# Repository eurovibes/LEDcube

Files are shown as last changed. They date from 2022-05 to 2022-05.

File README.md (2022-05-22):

<!-- SPDX-FileCopyrightText: 2021 Benedikt Spranger <b.spranger@linutronix.de> -->
<!-- SPDX-License-Identifier: CERN-OHL-S-2.0 -->


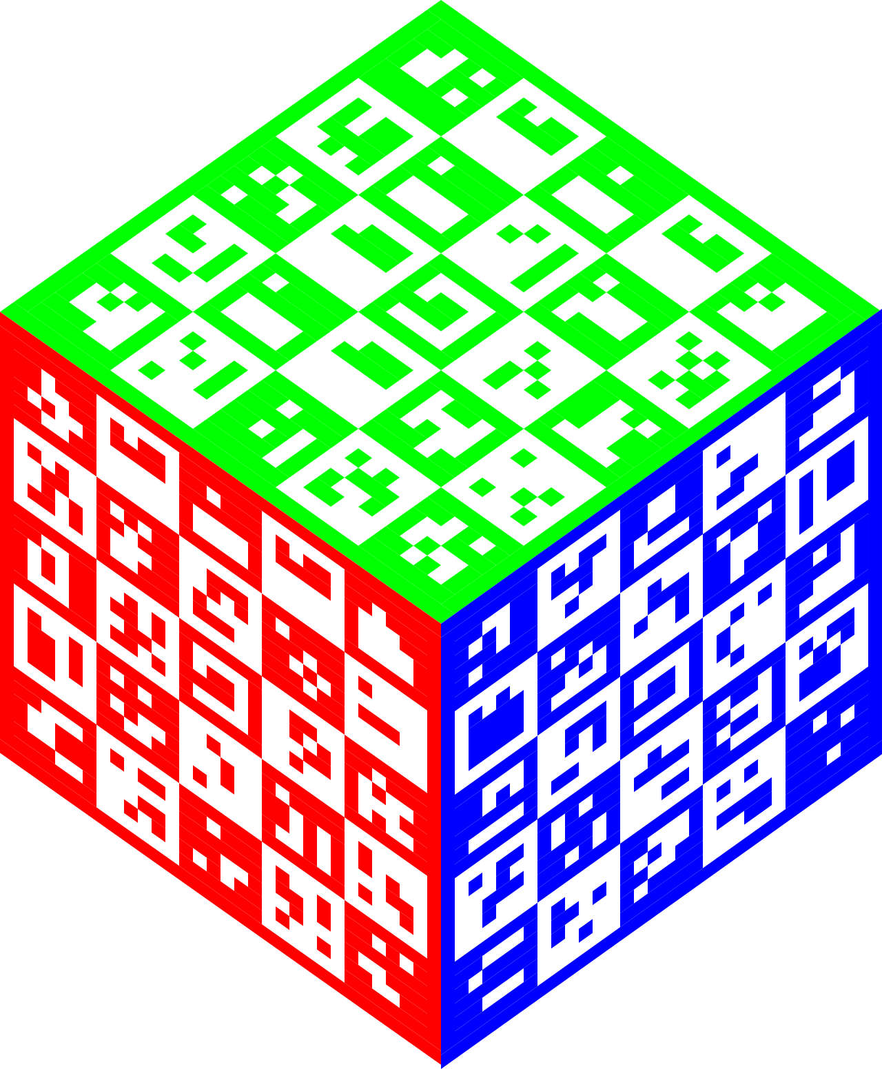
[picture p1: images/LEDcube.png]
LEDcube logo


# LEDcube -  Olimex STMP157-OLinuXino-LIME2 Sensor and Motor shield

## License rules

LEDcube is provided under the terms of the CERN-OHL-S license
version 2 as provided in the LICENSES/CERN-OHL-S-2.0 file.

Instead of adding license boilerplates to the individual files,
LEDcube uses SPDX license identifiers, which are machine parseable
and considered legaly equivalent.

The SPDX license identifier in LEDcube shall be added at the first
possible line in a file which can contain a comment. This is normally the
first line except for scripts. Scripts require the #!PATH_TO_INTERPRETER tag
in the first line; place the SPDX identifier into the second line.

The SPDX license identifier is added in form of a comment.

## Copyright and License

> Copyright Benedikt Spranger 2021.
> This source describes Open Hardware and is licensed under the CERNOHL-S v2.
> You may redistribute and modify this source and make products using it
> under the terms of the CERN-OHL-S v2 (https://ohwr.org/cern ohl s v2.txt ).
> This source is distributed WITHOUT ANY EXPRESS OR IMPLIED WARRANTY, INCLUDING
> OF MERCHANTABILITY, SATISFACTORY QUALITY AND FITNESS FOR A PARTICULAR PURPOSE.
> Please see the CERN-OHL-S v2 for applicable conditions.
> Source location: https://github.com/eurovibes/LEDcube
> As per CERN-OHL-S v2 section 4, should You produce hardware based
> on this source, You must where practicable maintain the Source Location
> visible on the external case of the LEDcube or other products you
> make using this source.

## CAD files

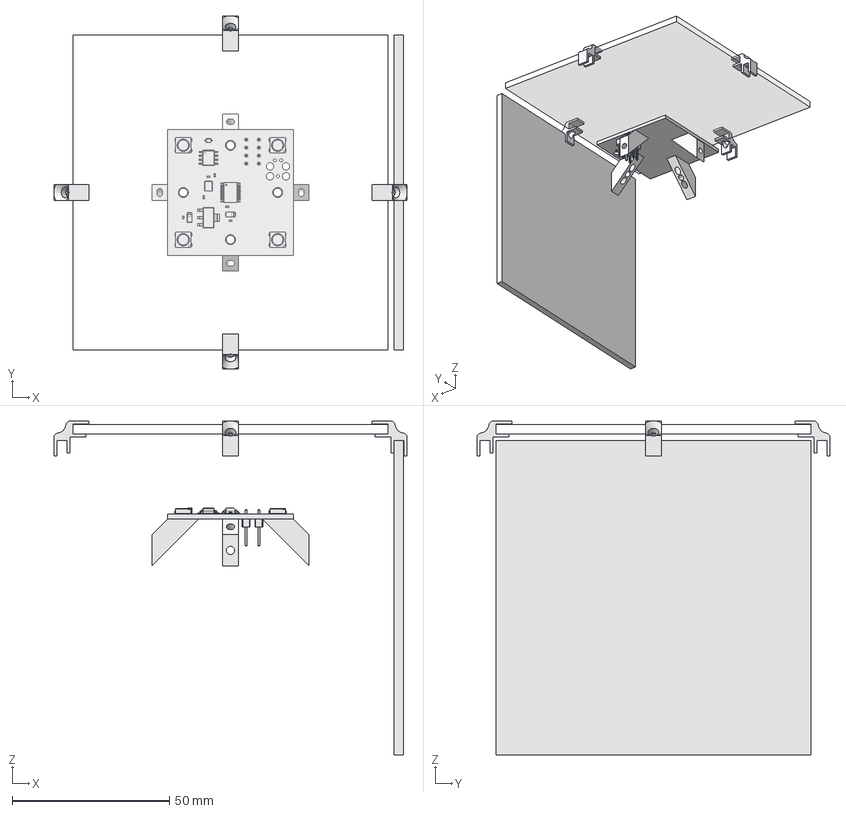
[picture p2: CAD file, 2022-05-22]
enclosure/LEDcube.FCStd
112.2 x 112.2 x 106.1 mm
LEDcube
Plexi
Halter
Halter1
Halter2
Halter3
Plexi1

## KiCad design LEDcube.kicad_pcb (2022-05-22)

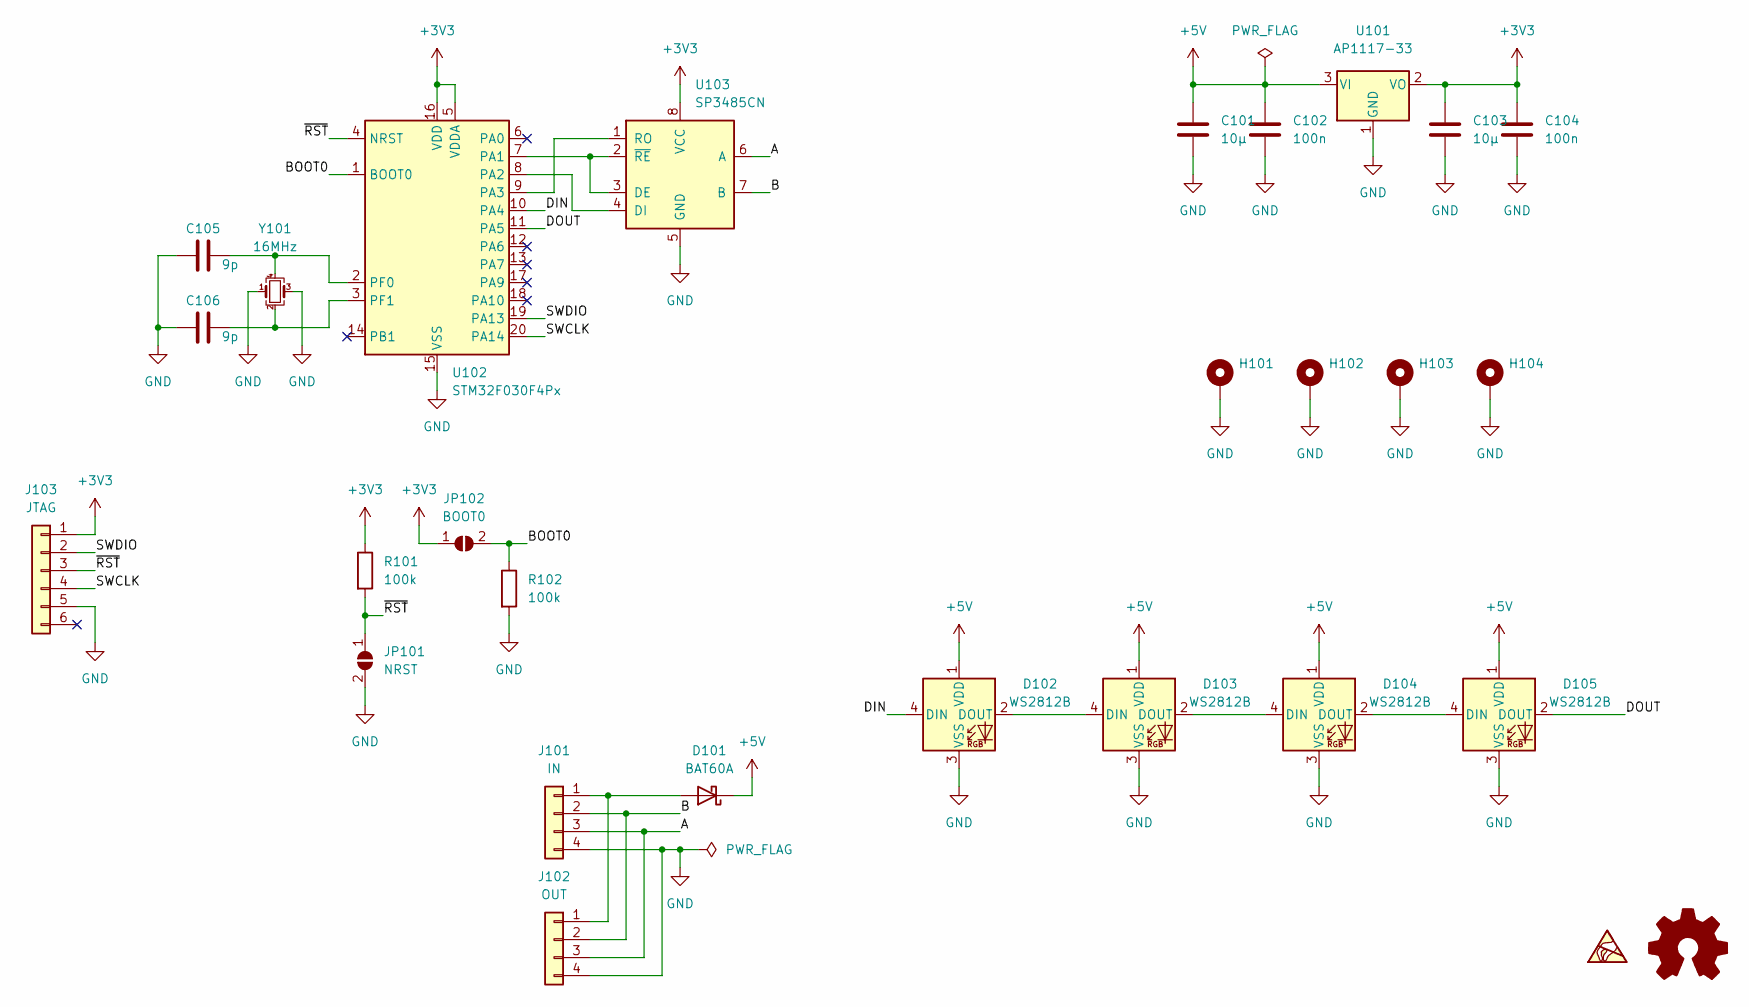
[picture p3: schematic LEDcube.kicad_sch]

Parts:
C101, C103: 10µ; CP_EIA-3216-18_Kemet-A; ManuPart# TAJA106K016RNJ; LCSC# C7171
C102, C104: 100n; C_0402_1005Metric; ManuPart# CL05B104KO5NNNC; LCSC# C1525
C105, C106: 9p; C_0402_1005Metric; ManuPart# CL05C100JB5NNNC; LCSC# C32949
D101: BAT60A; D_SOD-323; ManuPart# BAT60AE6327H; LCSC# C520634
D102, D103, D104, D105: WS2812B; LED_WS2812B_PLCC4_5.0x5.0mm_P3.2mm; ManuPart# WS2812B-B/W; LCSC# C2761795
H101, H102, H103, H104: MountingHole_3.2mm_M3_ISO14580_Pad
J101: IN; PinHeader_1x04_P2.54mm_Vertical
J102: OUT; PinHeader_1x04_P2.54mm_Vertical
J103: JTAG; Tag-Connect_TC2030-IDC-FP_2x03_P1.27mm_Vertical
JP101: NRST; SolderJumper-2_P1.3mm_Open_RoundedPad1.0x1.5mm
JP102: BOOT0; SolderJumper-2_P1.3mm_Open_RoundedPad1.0x1.5mm
R101, R102: 100k; R_0402_1005Metric
U101: AP1117-33; SOT-223-3_TabPin2; ManuPart# AP1117E33G-13; LCSC# C108785
U102: STM32F030F4Px; TSSOP-20_4.4x6.5mm_P0.65mm; ManuPart# STM32F030F4P6TR; LCSC# C89040
U103: SP3485CN; SOIC-8_3.9x4.9mm_P1.27mm; ManuPart# SP3485EN-L/TR; LCSC# C8963
Y101: 16MHz; Crystal_SMD_3225-4Pin_3.2x2.5mm; ManuPart# X322516MLB4SI; LCSC# C13738

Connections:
+3V3: C103.2, C104.2, J103.1, JP102.1 (A), R101.1, U101.2 (VO), U102.5 (VDDA), U102.16 (VDD), U103.8 (VCC)
+5V: C101.2, C102.2, D101.1 (K), D102.1 (VDD), D103.1 (VDD), D104.1 (VDD), D105.1 (VDD), U101.3 (VI)
/A: J101.3, J102.3, U103.6 (A)
/B: J101.2, J102.2, U103.7 (B)
/BOOT0: JP102.2 (B), R102.1, U102.1 (BOOT0)
/DIN: D102.4 (DIN), U102.10 (PA4)
/DOUT: D105.2 (DOUT), U102.11 (PA5)
/SWCLK: J103.4, U102.20 (PA14)
/SWDIO: J103.2, U102.19 (PA13)
/~RST: J103.3, JP101.1 (A), R101.2, U102.4 (NRST)
GND: C101.1, C102.1, C103.1, C104.1, C105.1, C106.1, D102.3 (VSS), D103.3 (VSS), D104.3 (VSS), D105.3 (VSS), H101.1, H102.1, H103.1, H104.1, J101.4, J102.4, J103.5, JP101.2 (B), R102.2, U101.1 (GND), U102.15 (VSS), U103.5 (GND), Y101.1, Y101.3
unnamed: C105.2, U102.2 (PF0), Y101.4
unnamed: C106.2, U102.3 (PF1), Y101.2
unnamed: D101.2 (A), J101.1, J102.1
unnamed: D102.2 (DOUT), D103.4 (DIN)
unnamed: D103.2 (DOUT), D104.4 (DIN)
unnamed: D104.2 (DOUT), D105.4 (DIN)
unnamed: U102.7 (PA1), U103.2 (~RE), U103.3 (DE)
unnamed: U102.8 (PA2), U103.4 (DI)
unnamed: U102.9 (PA3), U103.1 (RO)

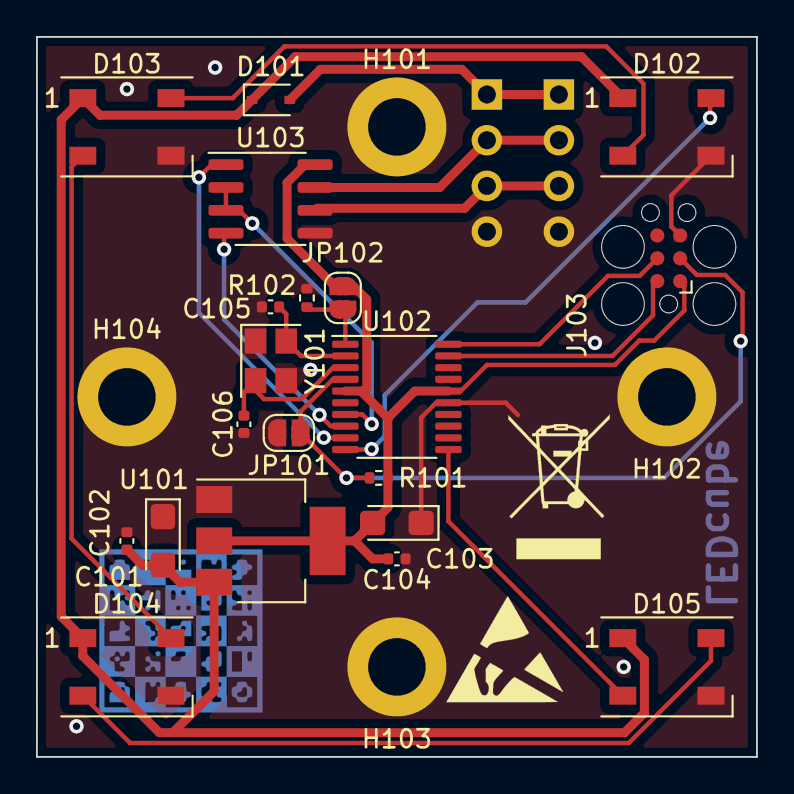
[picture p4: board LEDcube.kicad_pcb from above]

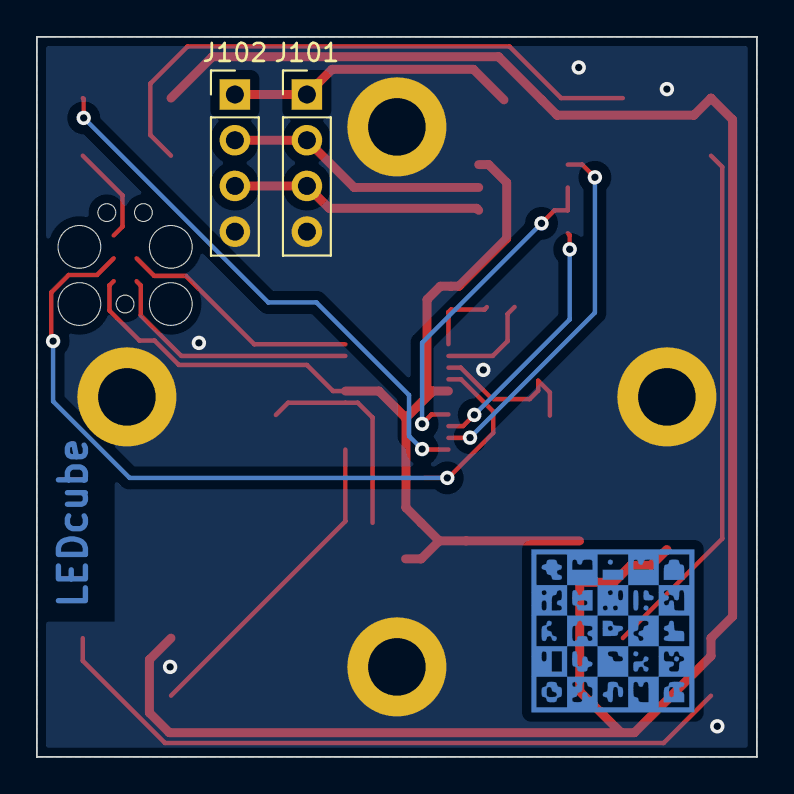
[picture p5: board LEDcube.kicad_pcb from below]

Board: 2 copper layers, 40.0 x 40.0 mm, 29 parts (3 on the bottom side), 20 nets.

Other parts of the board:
SYM1: LOGO
SYM2: WEEE-Logo_5.6x8mm_SilkScreen
SYM3: ESD-Logo_6.6x6mm_SilkScreen

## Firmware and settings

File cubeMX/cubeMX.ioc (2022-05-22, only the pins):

Mcu.UserName=STM32F030F4Px
PA1.Signal=USART1_DE
PA13.Signal=SYS_SWDIO
PA14.Signal=SYS_SWCLK
PA2.Signal=USART1_TX
PA3.Signal=USART1_RX
PA4.GPIO_Label=DIN
PA4.Signal=GPIO_Input
PA5.GPIO_Label=DOUT
PA5.Signal=GPIO_Output
PF0-OSC_IN.Signal=RCC_OSC_IN
PF1-OSC_OUT.Signal=RCC_OSC_OUT

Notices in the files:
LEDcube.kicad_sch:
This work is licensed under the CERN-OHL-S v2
